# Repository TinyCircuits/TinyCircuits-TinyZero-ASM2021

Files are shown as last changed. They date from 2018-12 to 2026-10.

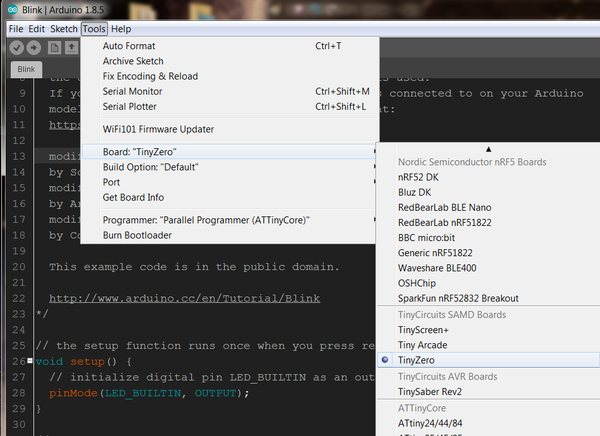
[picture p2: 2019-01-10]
images/tutorial_images/ASM2021-Tutorial-Picture-08.png

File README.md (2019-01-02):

# TinyCircuits TinyZero Processor Board
# ASM2021 Rev5

These are the design files for the TinyCircuits ASM2021 Rev 5 PCB.  This is a Tiny processor board (Square Version, 20mm x 20mm) that uses the same microcontroller (Atmel ATSAMD21G18A) as the Arduino Zero and has stackable TinyShield support.  

Format is in Cadsoft Eagle format - Eagle version 6.2 was used for the original design.

For more infomation on this, check out the product page at TinyCircuits.com:  https://tinycircuits.com/products/tinyzero-processor

# License:

Design by TinyCircuits.
All design files are released under the Creative Commons Attribution Share-Alike 3.0 License, see the following link for details: http://creativecommons.org/licenses/by-sa/3.0

All text above must be included in any redistribution or derived design

This project uses designs and concepts developed as part of the Arduino project and the LilyPad project.  The TinyCircuits design files themselves (schematics, PCB and libraries) are not directly derived from these works' design files and have been created new, however the concepts and basic architecture behind the TinyDuino and TinyLily products are derived and we thank the hard work of the organizations below for their contributions to open-source hardware:
  
Original Arduino Uno Design by Team Arduino

LilyPad Arduino Design by Leah Buechley and Sparkfun Electronics

Please support the open-source hardware community

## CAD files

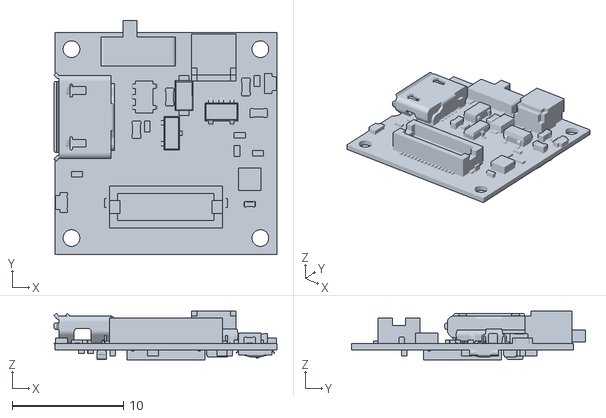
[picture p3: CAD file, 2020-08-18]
cad/TinyZero_ASM2021_REV5-STL.stl
20.1 x 21.1 x 4.37

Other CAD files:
cad/TinyZero_ASM2001_REV5-DETAILED_DRAWING-DXF.dxf

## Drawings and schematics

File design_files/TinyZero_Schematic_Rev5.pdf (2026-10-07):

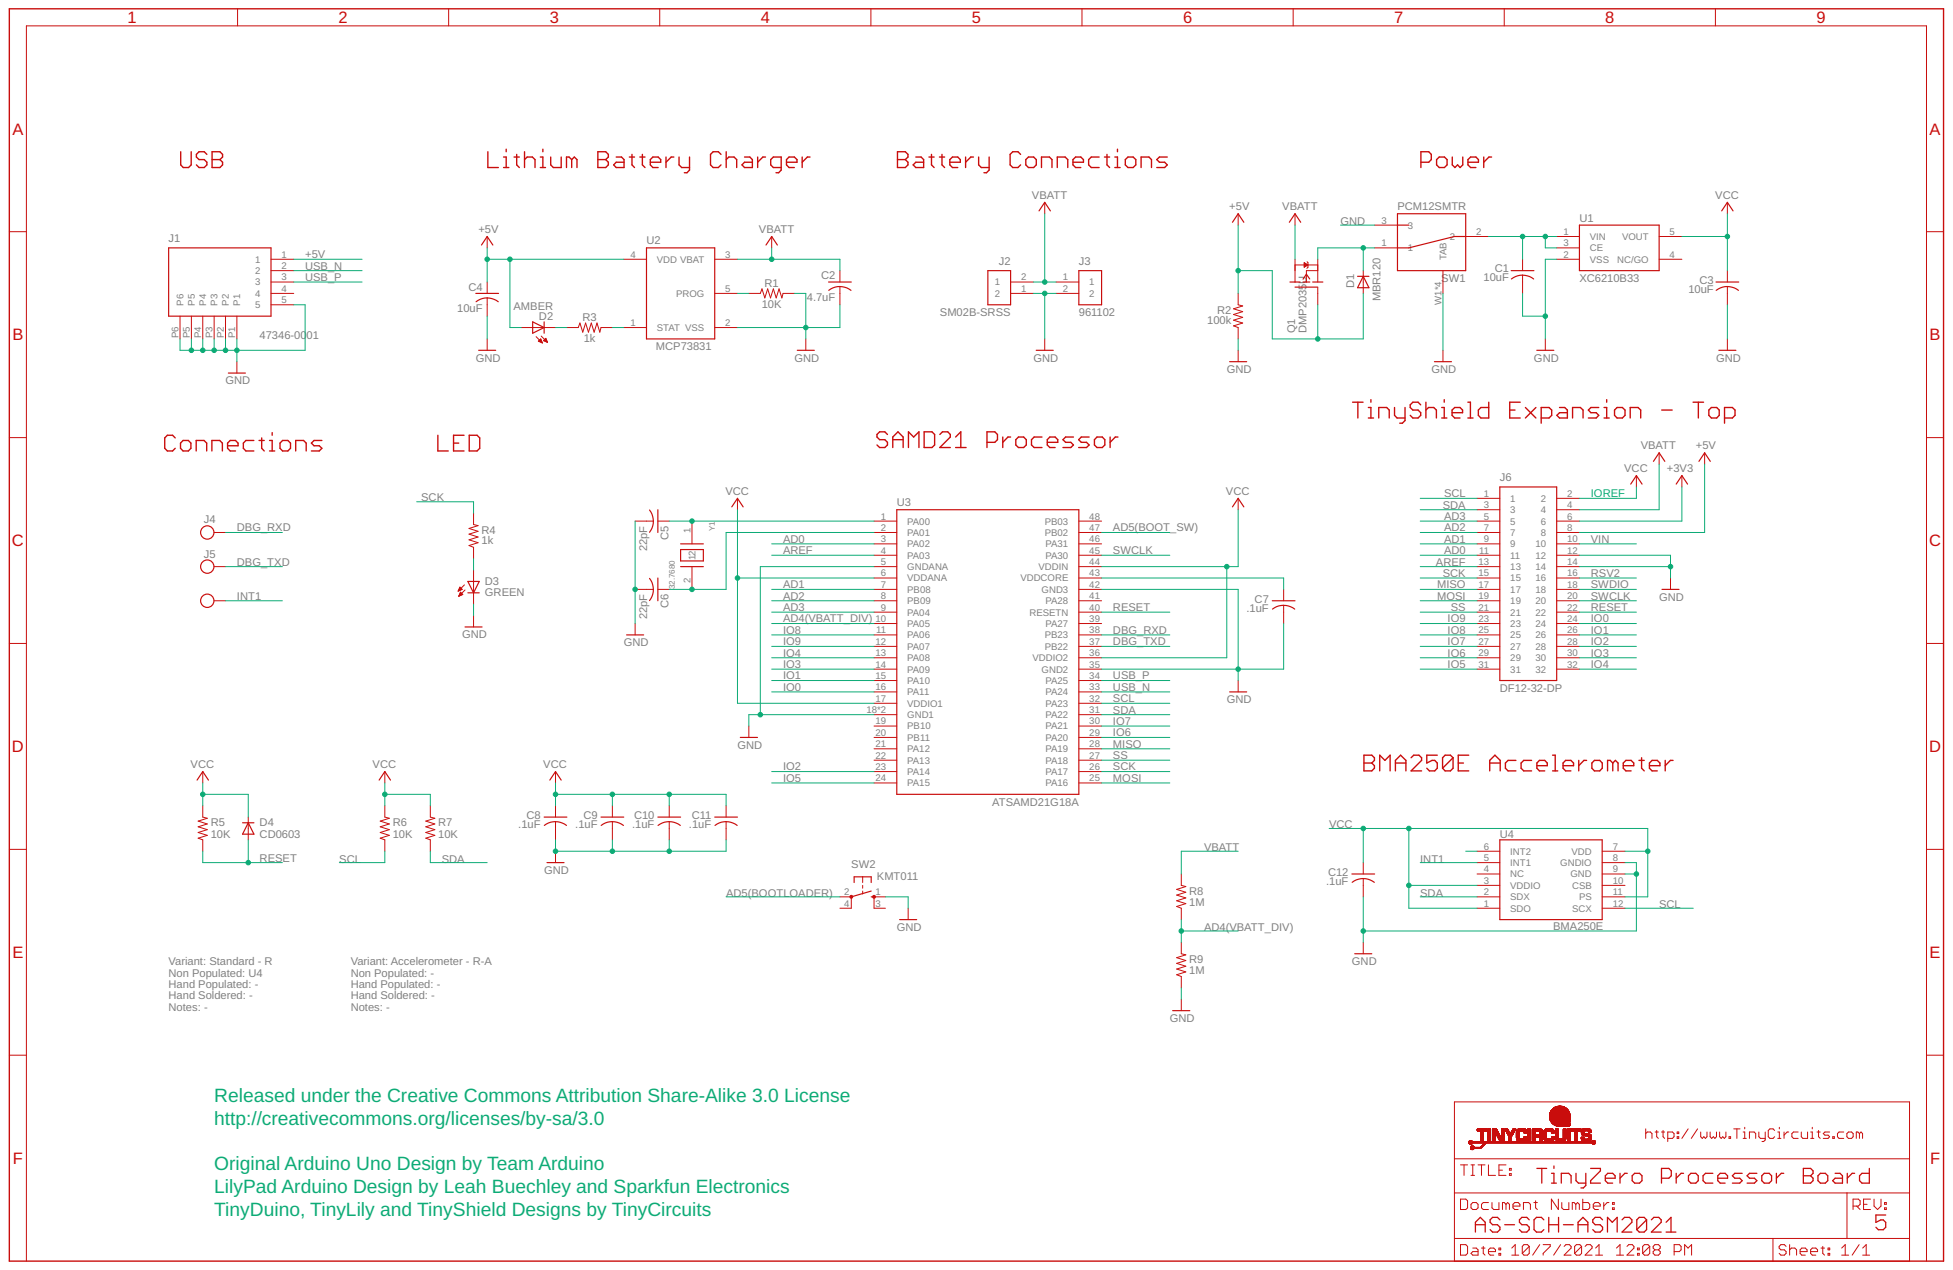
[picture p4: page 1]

Hand Populated: - Hand Soldered: - Notes: - Variant: Standard - R
Non Populated: U4

Non Populated: - Hand Populated: - Hand Soldered: - Notes: - Variant: Accelerometer - R-A

Released under the Creative Commons Attribution Share-Alike 3.0 License
http://creativecommons.org/licenses/by-sa/3.0

Original Arduino Uno Design by Team Arduino
LilyPad Arduino Design by Leah Buechley and Sparkfun Electronics
TinyDuino, TinyLily and TinyShield Designs by TinyCircuits

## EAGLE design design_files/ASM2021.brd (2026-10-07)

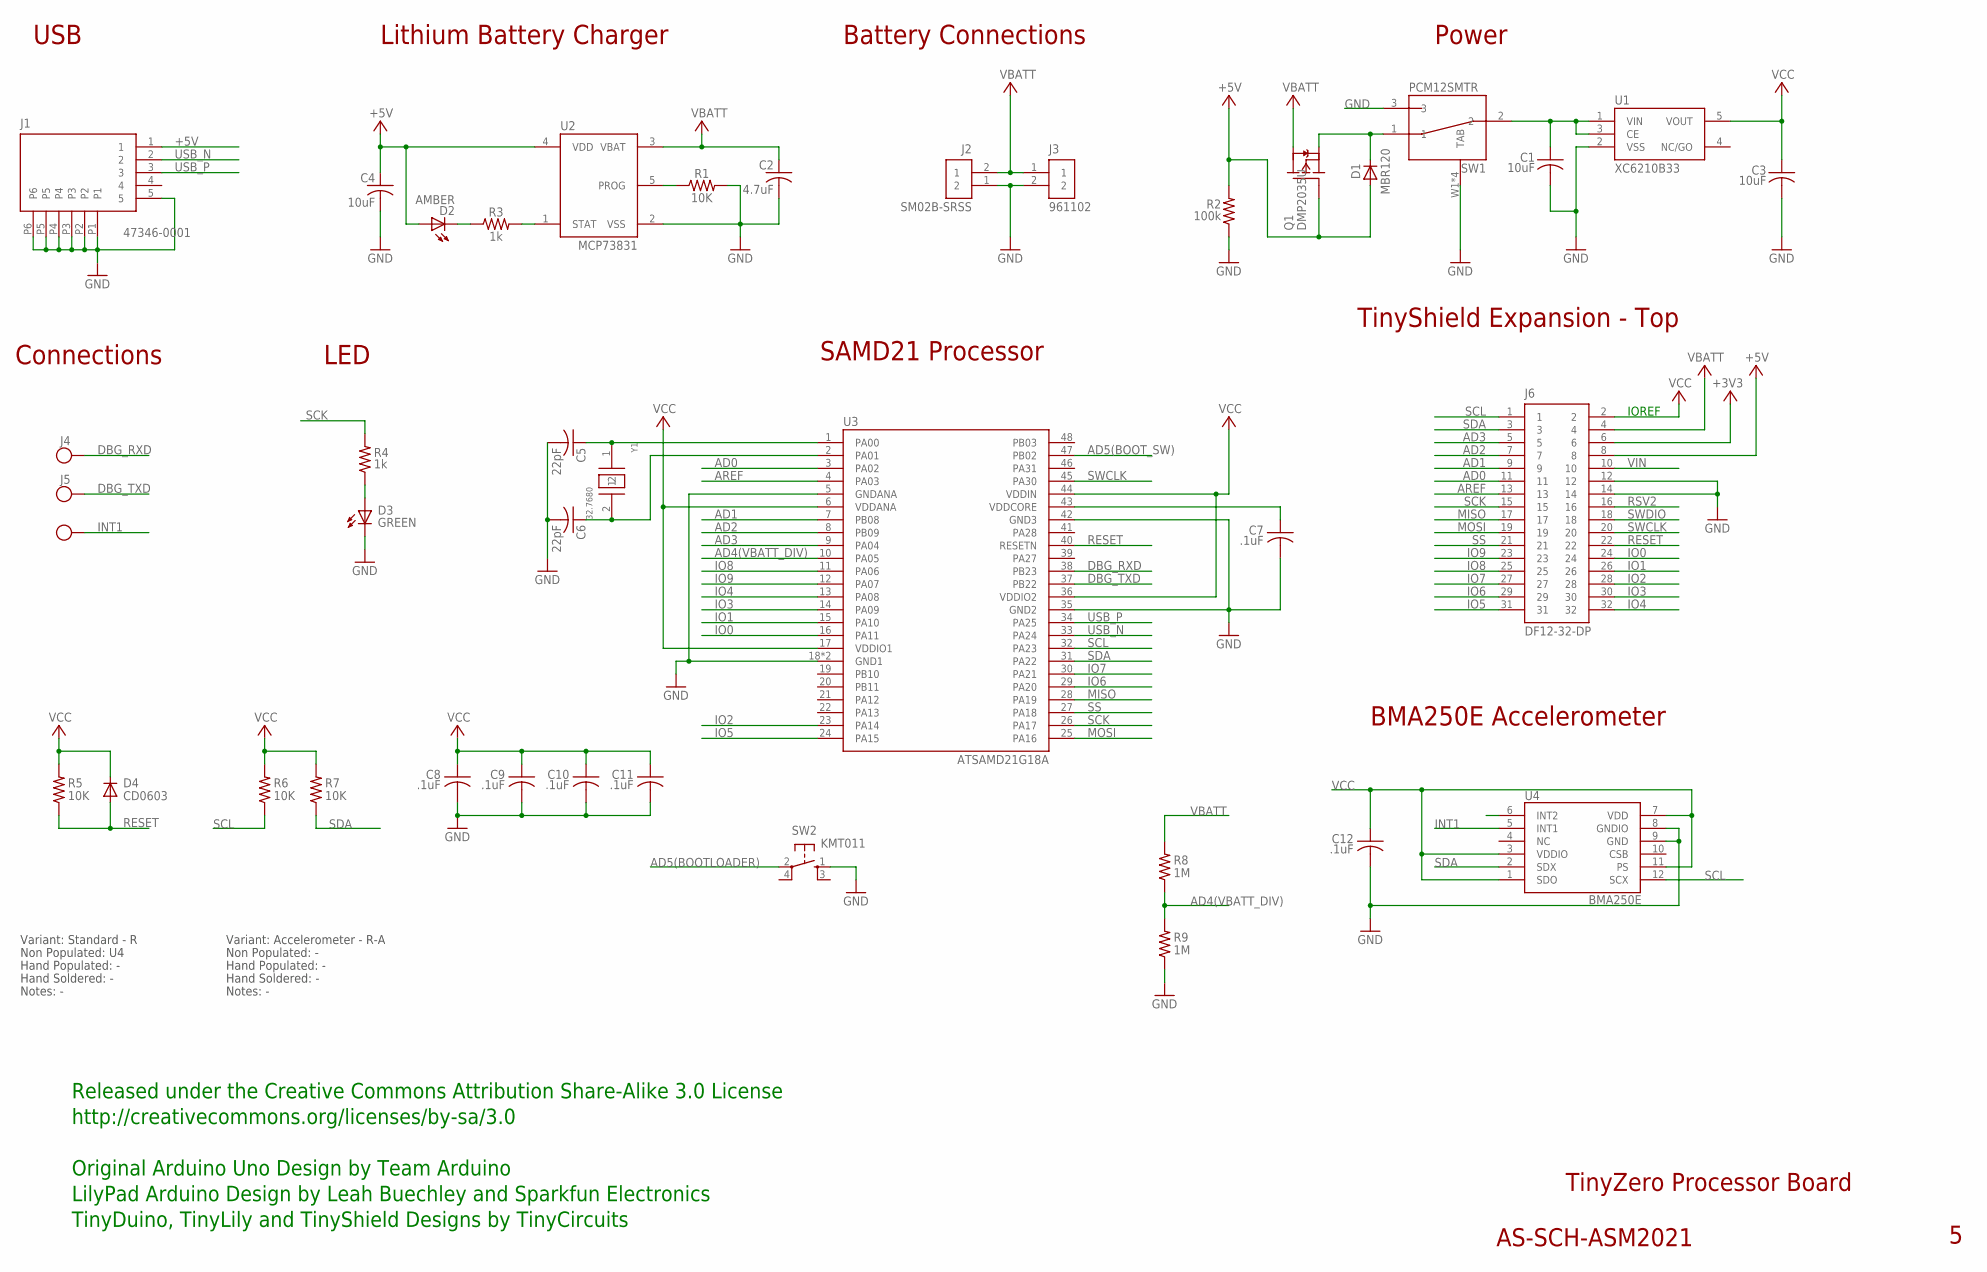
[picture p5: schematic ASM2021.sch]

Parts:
C1, C3, C4: 10uF; C0603; PARTNO AS-ITM-00002
C2: 4.7uF; C0603; PARTNO AS-ITM-00088
C5, C6: 22pF; C0402; PARTNO AS-ITM-00211
C7, C8, C9, C10, C11, C12: .1uF; C0402; PARTNO AS-ITM-00008
D1: MBR120; SOD-123FL
D2: AMBER; LNJ_LED; PARTNO AS-ITM-00026
D3: GREEN; LNJ_LED; PARTNO AS-ITM-00011
D4: CD0603; 0603; PARTNO AS-ITM-00009
J1: 47346-0001; MICRO_USB
J2: SM02B-SRSS; JST_SH_2X1
J3: 961102; 2X.1"
J4, J5: TEST_POINT; TEST_POINT_1MM
J6: DF12-32-DP; PARTNO AS-ITM-00015
Q1: DMP2035U; SOT23
R1: 10K; 0402
R2: 100k; 0402; PARTNO AS-ITM-00004
R3, R4: 1k; 0402; PARTNO AS-ITM-00003
R5, R6, R7: 10K; 0402; PARTNO AS-ITM-00032
R8, R9: 1M; 0402; PARTNO AS-ITM-00005
SW1: PCM12SMTR
SW2: KMT011
U1: XC6210B33; SOT-25
U2: MCP73831; SOT-23
U3: ATSAMD21G18A; QFN48; PARTNO AS-ITM-00273
U4: BMA250E; 3-AXIS_ACCELEROMETER
Y1: 32.7680; ABS06; PARTNO AS-ITM-00279

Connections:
+3V3: J6.6
+5V: C4.1, D1.A, D2.A, J1.1, J6.8, Q1.B (G), R2.2, U2.4 (VDD)
AD0: J6.11, U3.3 (PA02)
AD1: J6.9, U3.7 (PB08)
AD2: J6.7, U3.8 (PB09)
AD3: J6.5, U3.9 (PA04)
AD4(VBATT_DIV): R8.1, R9.2, U3.10 (PA05)
AD5(BOOTLOADER): SW2.2
AD5(BOOT_SW): U3.47 (PB02)
AREF: J6.13, U3.4 (PA03)
DBG_RXD: J4.P$1, U3.38 (PB23)
DBG_TXD: J5.P$1, U3.37 (PB22)
GND: C1.2, C2.2, C3.2, C4.2, C5.2, C6.2, C7.2, C8.2, C9.2, C10.2, C11.2, C12.2, D3.C, J1.5, J1.P1, J1.P2, J1.P3, J1.P4, J1.P5, J1.P6, J2.1 (2), J3.2, J6.12, J6.14, R1.2, R2.1, R9.1, SW1.3, SW1.W1 (TAB), SW1.W2 (TAB), SW1.W3 (TAB), SW1.W4 (TAB), SW2.1, U1.2 (VSS), U2.2 (VSS), U3.5 (GNDANA), U3.18 (GND1), U3.35 (GND2), U3.42 (GND3), U3.EXP (GND1), U4.8 (GNDIO), U4.9 (GND)
INT1: U4.5 (INT1)
IO0: J6.24, U3.16 (PA11)
IO1: J6.26, U3.15 (PA10)
IO2: J6.28, U3.23 (PA14)
IO3: J6.30, U3.14 (PA09)
IO4: J6.32, U3.13 (PA08)
IO5: J6.31, U3.24 (PA15)
IO6: J6.29, U3.29 (PA20)
IO7: J6.27, U3.30 (PA21)
IO8: J6.25, U3.11 (PA06)
IO9: J6.23, U3.12 (PA07)
MISO: J6.17, U3.28 (PA19)
MOSI: J6.19, U3.25 (PA16)
unnamed: C5.1, U3.1 (PA00), Y1.1
unnamed: D1.C, Q1.E (S), SW1.1
unnamed: C6.1, U3.2 (PA01), Y1.2
unnamed: D3.A, R4.1
unnamed: D2.C, R3.1
unnamed: R1.1, U2.5 (PROG)
unnamed: R3.2, U2.1 (STAT)
unnamed: C7.1, U3.43 (VDDCORE)
RESET: D4.A, J6.22, R5.1, U3.40 (RESETN)
RSV2: J6.16
SCK: J6.15, R4.2, U3.26 (PA17)
SCL: J6.1, R6.1, U3.32 (PA23), U4.12 (SCX)
SDA: J6.3, R7.1, U3.31 (PA22), U4.2 (SDX)
SS: J6.21, U3.27 (PA18)
SWCLK: J6.20, U3.45 (PA30)
SWDIO: J6.18
USB_N: J1.2, U3.33 (PA24)
USB_P: J1.3, U3.34 (PA25)
VBATT: C2.1, J2.2 (1), J3.1, J6.4, Q1.C (D), R8.2, U2.3 (VBAT)
VCC: C3.1, C8.1, C9.1, C10.1, C11.1, C12.1, D4.C, J6.2, R5.2, R6.2, R7.2, U1.5 (VOUT), U3.6 (VDDANA), U3.17 (VDDIO1), U3.36 (VDDIO2), U3.44 (VDDIN), U4.1 (SDO), U4.3 (VDDIO), U4.7 (VDD), U4.11 (PS)
VCC_IN: C1.1, SW1.2, U1.1 (VIN), U1.3 (CE)
VIN: J6.10

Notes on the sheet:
IOREF
TinyShield Expansion - Top
SAMD21 Processor
Power
LED
TinyZero Processor Board
AS-SCH-ASM2021
Released under the Creative Commons Attribution Share-Alike 3.0 License
http://creativecommons.org/licenses/by-sa/3.0
Original Arduino Uno Design by Team Arduino
TinyDuino, TinyLily and TinyShield Designs by TinyCircuits
LilyPad Arduino Design by Leah Buechley and Sparkfun Electronics
Lithium Battery Charger
Battery Connections
USB
BMA250E Accelerometer
Connections
Non Populated: U4
Hand Populated: -
Hand Soldered: -
Notes: -
Variant: Standard - R
Non Populated: -
Variant: Accelerometer - R-A

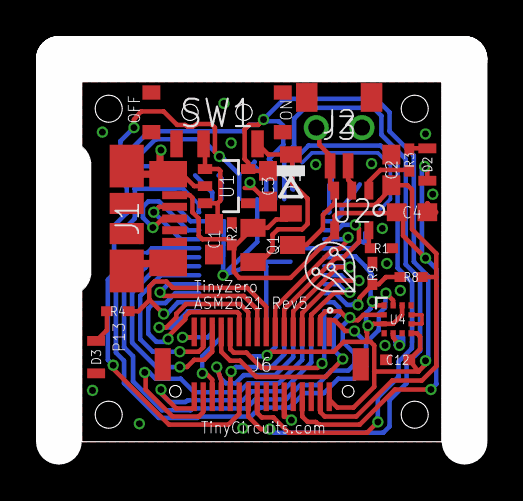
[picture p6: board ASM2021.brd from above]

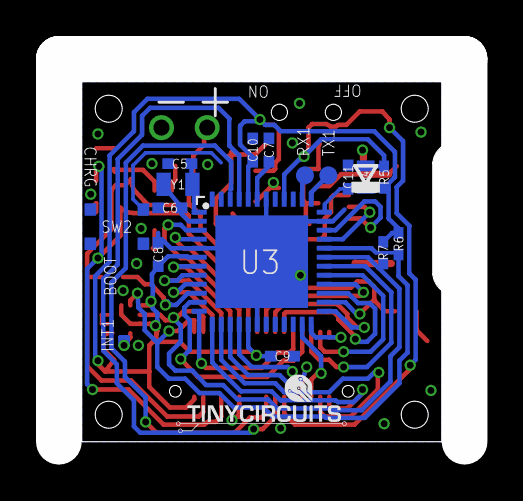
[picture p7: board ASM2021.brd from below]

Board: 2 copper layers, 20.0 x 20.0 mm, 40 parts (16 on the bottom side), 41 nets.

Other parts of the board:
U$1: DOCFIELD-TINYCIRCUITS-PCB

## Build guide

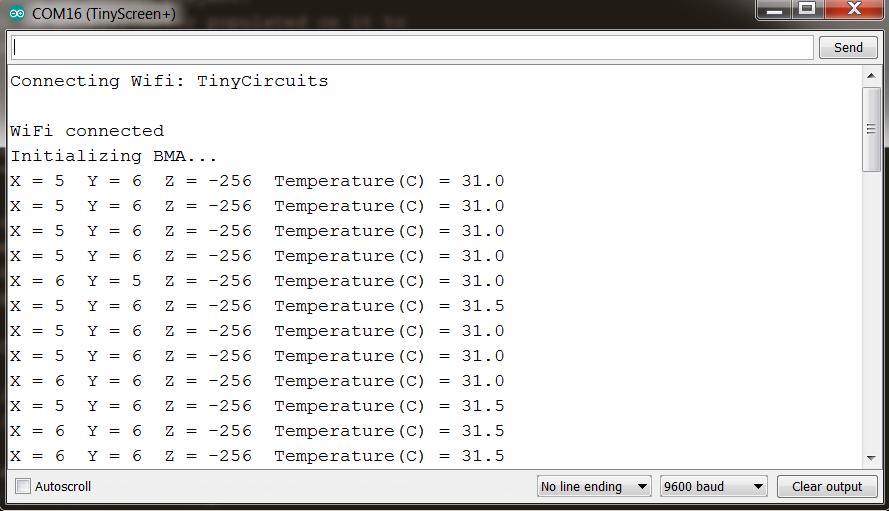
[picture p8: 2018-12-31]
images/Accel_Cayenne_Tutorial/Serialmonitor_monitoring.png

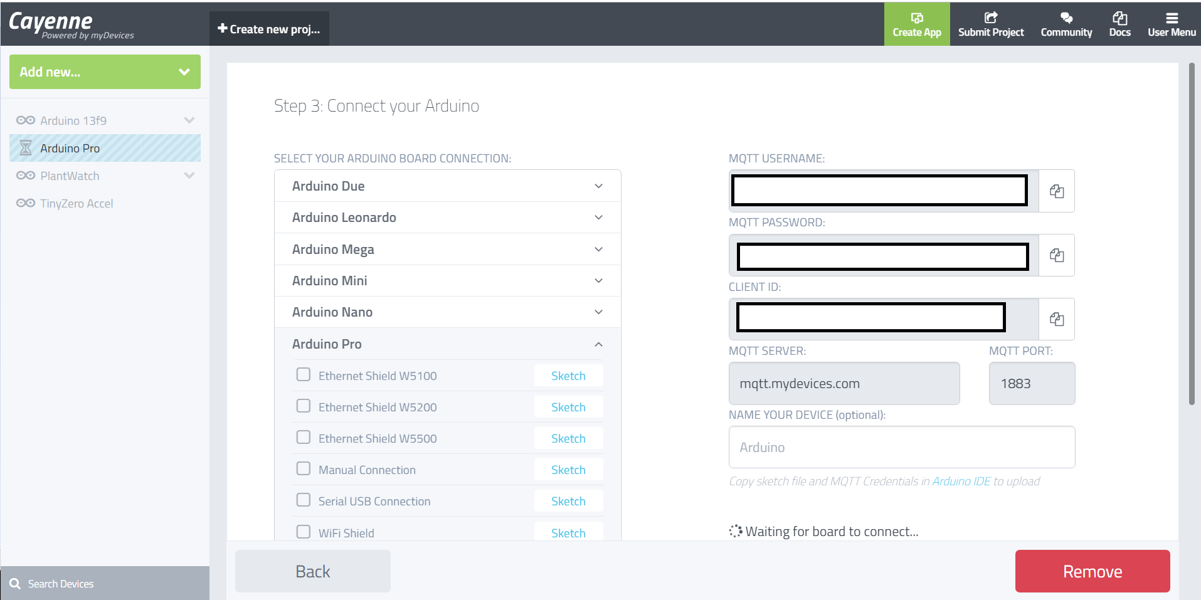
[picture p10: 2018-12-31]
images/Accel_Cayenne_Tutorial/cayenne_mqtt_passwords.png

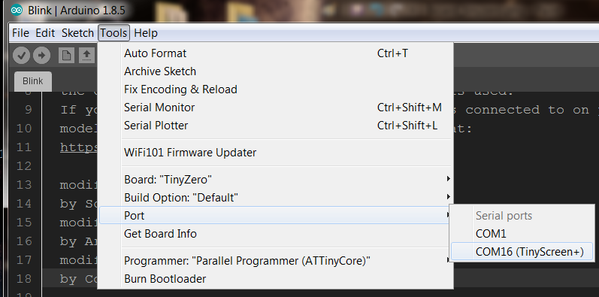
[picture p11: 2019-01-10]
images/tutorial_images/ASM2021-Tutorial-Picture-09.png

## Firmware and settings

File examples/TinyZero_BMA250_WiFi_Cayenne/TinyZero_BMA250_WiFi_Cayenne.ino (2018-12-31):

/*************************************************************************
 * BMA250 TinyZero Accelerometer Internet of Things Project: 
 * This program uses the TinyZero with an accelerometer populated on it to 
 * connect to WiFi for a Cayenne Internet of Things application
 * 
 * Hardware by: TinyCircuits
 * BMA250 Library by: TinyCircuits
 * Code by: Laverena Wienclaw for TinyCircuits
 ************************************************************************/

#include <Wire.h>         // For I2C communication with sensor
#include <WiFi101.h>      // For connecting to WiFi
#include "BMA250.h"       // For interfacing with the accel. sensor
#include <CayenneMQTTWiFi101.h> // Cayenne library to connect to transmit data 

/*********************** EDIT THIS SECTION TO MATCH YOUR INFO *************************/
// WiFi network information
char ssid[] = "TinyCircuits";        //  your network SSID (name)
char wifiPassword[] = "__________";  // your network password

// Cayenne authentication info. This should be obtained from the Cayenne Dashboard.
char username[] = "________________________________________";
char password[] = "________________________________________";
char clientID[] = "________________________________________";
/*************************************************************************************/

// Accelerometer sensor variables for the sensor and its values
BMA250 accel_sensor;
int x, y, z;
double temp;

void setup() {
  SerialUSB.begin(9600);
  Wire.begin();
  WiFi.setPins(8, 2, A3, -1); // VERY IMPORTANT FOR TINYCIRCUITS WIFI SHIELD

  while (!SerialUSB); // ***Will halt program until the Serial Monitor is opened***

  // Connect to WiFi and Cayenne
  connectWifi();
  Cayenne.begin(username, password, clientID);

  // Set up the BMA250 acccelerometer sensor
  SerialUSB.print("Initializing BMA..."); SerialUSB.println();
  accel_sensor.begin(BMA250_range_2g, BMA250_update_time_64ms); 
}

void loop() {
  // Take sensor reading and print to Serial Monitor
  accel_sensor.read(); //This function gets new data from the acccelerometer

  // Get the acceleration values from the sensor and store them into global variables
  // (Makes reading the rest of the program easier)
  x = accel_sensor.X;
  y = accel_sensor.Y;
  z = accel_sensor.Z;
  temp = ((accel_sensor.rawTemp * 0.5) + 24.0);

  // Call function to display sensor readings on Serial Monitor
  showSerial();

  // Report sensor reading to Cayenne
  Cayenne.loop();
  delay(2000); // delay before looping again to take new reading
}

// Prints the sensor values to the Serial Monitor (found under 'Tools')
void showSerial() {
  SerialUSB.print("X = ");
  SerialUSB.print(x);
  
  SerialUSB.print("  Y = ");
  SerialUSB.print(y);
  
  SerialUSB.print("  Z = ");
  SerialUSB.print(z);
  
  SerialUSB.print("  Temperature(C) = ");
  SerialUSB.println(temp);
}

// This function goes through the steps to connect to WiFi using the WiFi101 library
void connectWifi(void){
  // Connect to Wifi network:
  SerialUSB.print("Connecting Wifi: ");
  SerialUSB.println(ssid);
  WiFi.begin(ssid, wifiPassword);

  // Loop until connection is secured
  while (WiFi.status() != WL_CONNECTED)
    SerialUSB.print(".");
    delay(500);

  // Success message and put WiFi in low power mode to save energy
  WiFi.maxLowPowerMode();
  SerialUSB.println("");
  SerialUSB.println("WiFi connected");
}

// Default function for sending sensor data at intervals to Cayenne.
CAYENNE_OUT_DEFAULT()
{
  // Write data to Cayenne here:
  Cayenne.virtualWrite(1, x);
  Cayenne.virtualWrite(2, y);
  Cayenne.virtualWrite(3, z);
  Cayenne.virtualWrite(4, temp);
}

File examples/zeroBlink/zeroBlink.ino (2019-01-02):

//-------------------------------------------------------------------------------
//  TinyCircuits TinyZero Blink
//  Last Updated 28 Nov 2018
//  
//  Blink! If an accelerometer is present, change the rate of blinking according
//  to the Z axis sensor value.
//
//  Written by Ben Rose for TinyCircuits, https://tinycircuits.com
//
//-------------------------------------------------------------------------------


#include <Wire.h>
#include "BMA250.h"

BMA250 accel;

void setup() {
  pinMode(13, OUTPUT);
  Wire.begin();
  delay(20);
  if (!accel.begin(BMA250_range_2g, BMA250_update_time_32ms)) {
    while (1) {
      digitalWrite(13, HIGH);
      accel.read();
      delay(pow(abs(accel.Z),0.75)*4);
      digitalWrite(13, LOW);
      accel.read();
      delay(pow(abs(accel.Z),0.75)*4);
    }
  }
}

// the loop function runs over and over again forever
void loop() {
  digitalWrite(13, HIGH);   // turn the LED on (HIGH is the voltage level)
  delay(1000);                       // wait for a second
  digitalWrite(13, LOW);    // turn the LED off by making the voltage LOW
  delay(1000);                       // wait for a second
}

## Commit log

2018-12-31 adding files
    [ASM2021.brd, ASM2021.sch]
2020-06-26 Add CAD data
2020-06-29 Rename files, add dxf, and use new template for 2D drawings
    [TinyZero_ASM2021_DXF_REV5.dxf]
2020-07-01 Remove vias in models & drawings, add compact dimension images, and remove file to reduce size
    [TinyZero_ASM2021_DXF_REV5.dxf, TinyZero_DXF_ASM2021_REV5.dxf]
2020-07-01 Add STL
    [TinyZero_STL_ASM2021_REV5.stl]
2020-07-02 Add zip of all CAD files
2020-08-18 Update CAD drawings
    [TinyZero_ASM2001_REV5-DETAILED_DRAWING-DXF.dxf, TinyZero_ASM2021_REV5-STL.stl, TinyZero_DXF_ASM2021_REV5.dxf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]
